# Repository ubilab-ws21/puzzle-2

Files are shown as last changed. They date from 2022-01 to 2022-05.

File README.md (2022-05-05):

# Team 2: Time will guide you!

## Contents
- [Story Overview](#1)
- [The Puzzle](#2)
- [Use Case Scenario](#3)
- [System Overview](#4)
- [Project Workflow](#5)
- [Hardware Overview](#6)
  - [Electronic Components](#7)
  - [The Box](#8) 
- [Software Overview](#9)
  - [Testing Individual Modules](#10)
  - [Building the Main Program](#11)
  - [Configuring OTA](#12)
  - [Establishing MQTT Communication](#13) 
- [References](#14)

## Story Overview 
A Solar strom themed Escape Room where players have to solve puzzles to get out of it. In the year 2032, the world revolving around automation and high-end technology. One fine day, a Solar Storm hits the city and all the servers and digital systems starts to fail there is a power breakdown. The players are stuck inside a server room having limited emergency backup. The goal is to upload the software to the server in order to get things back in place.   

## The Puzzle 
We are building a puzzle for the server room of the Solar Storm themed Escape Room in the Ubiquitous Laboratory Area-079 Escape Room. The puzzle is designed in regard to access the power delivery system which will be powering the automated door to open the server room and power up the server which contains the corrupted software. The emergency power backup can power up only a single server and if wrong switches are turned on the backup will drain out. 

The power switches are protected by a tap-tap pattern for which the players have to be aware and take the hints from the previous puzzle. Once you get the pattern right you get access to the power switches. But, there are lots of switches and you need to turn on few of them. One wrong switch can drain out the emergency backup. The order of the switches which needs to be turned on will be given by the puzzle displayed in the OLED Display. You get the right sequence of switches, the server room door opens and the server turns on.

## Use Case Scenario 
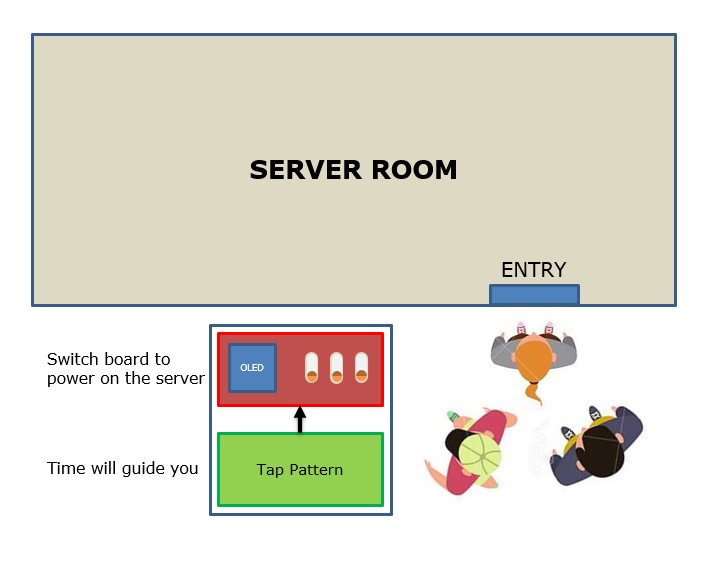
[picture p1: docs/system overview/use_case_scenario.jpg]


## System Overview 
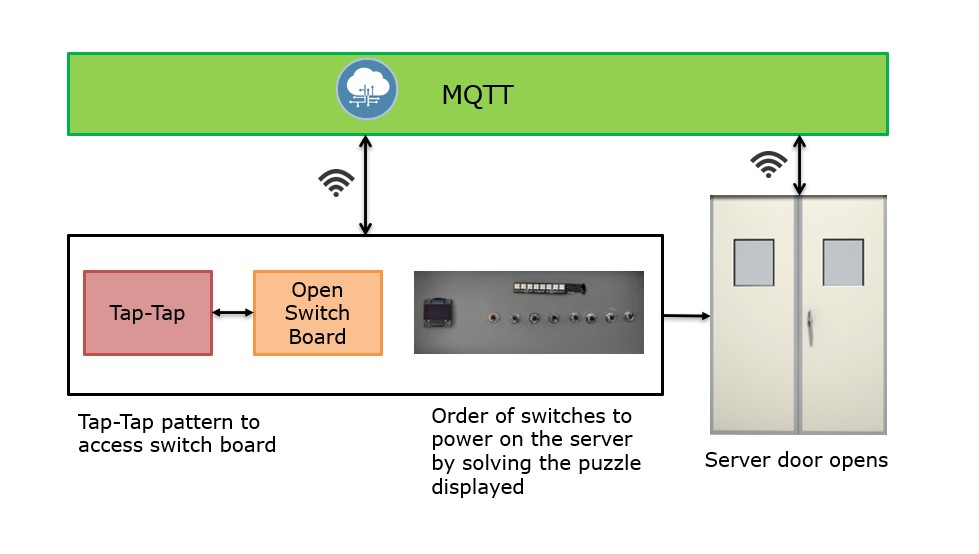
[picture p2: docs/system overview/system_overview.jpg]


## Project Workflow 
- [x] Figuring the puzzle according to the story
- [x] Creating a Bill of Materials (BOM)
- [x] Starting with ESP32 Programming and Basics of MQTT 
- [x] First tour of Escape Room
- [x] Testing all components
- [x] Preparing the circuit
- [x] Program the ESP Board
- [x] Prepare 3D Model
- [x] Print 3D Model
- [x] Design the outer casing
- [x] Assemble the outer casing
- [x] Solder the circuit in PCB
- [x] Assembling all components 
- [x] Testing and Bug Fixing
- [x] Prototype Presentation
- [x] Final Tweaking and Testing
- [x] Final run and presentation

## Hardware Overview 

##### Electronic Components 
- ESP-32 Microcontroller
- Servo Motor
- Piezo Buzzer
- OLED Display
- Toggle Switches
- 8x5050 RGB LED Strip
- Printed Circuit Board
- Connecting Wires

For more details, check [Bill of Materials](https://github.com/ubilab-ws21/puzzle-2/tree/main/docs/BOM).

##### The Box 
The outer casing and the servo hinge was designed using 3D Modelling. The model files can be found [here](https://github.com/ubilab-ws21/puzzle-2/tree/main/design).

## Software Overview 

##### Testing Individual Modules 
Firstly, we tested all the components and modules individually for better integration of our project. Each modules were tested with Arduino for understanding the basic functionality and then tested with ESP32 to check the compatibility. The codes for testing can be found [here](https://github.com/ubilab-ws21/puzzle-2/tree/main/src/test).

##### Building the Main Program 
Then, we integrated all the modules and modified in a single program to be fired up in the ESP32. The program manages the worflow of the puzzle and maintains proper communication with the MQTT server. It is also programmed in such a way that the ESP32 can receives updates Over-the-air. The main code can be found [here](https://github.com/ubilab-ws21/puzzle-2/tree/main/src/main). 

##### Configuring OTA 
In order to receive updates Over-the-air, the below function has been called inside the setup loop. The function sets up the host name and password for the ESP32 in the newtork and updates the ESP32 if there is any update request. Also, remember to include the appropriate header file.
```
#include <ArduinoOTA.h>

void setup(){
  ....
  ....
  setupOTA();
}
void loop(){
  ...
  ...
  ArduinoOTA.handle();
}
```
##### Establishing MQTT Communication 
The puzzle workflow totally depends on successful interaction between the operator and the arcape. The operator controls whether the puzzle is to be turned  `on` or `off` depending on the progess of the other puzzles. The programs subscribes from the topic `2/esp` and checks whether the trigger is on/off and works accordingly. Once the puzzle is `on`, the program publishes that the puzzle is `active` in the topics, `2/esp` and `game/puzzle2` for the operator and arcape resp. to understand that the puzzle is active. Otherwise the state is retained to `inactive` state.

###### Communication Format
All messages exchanged between the server and the client is JSON schema: 

```json
{
  "method": "<method>",
  "state": "<state>",
  "data": "<data>"
}
```
where,

| Method  | State | Description |
| :--- | :--- | :--- |
| status  | inactive, active, solved | Describes the current state of the puzzle |
| trigger | on, off | Contols the behaviour of the puzzle |

More information regarding MQTT server and the communication protocols can be found [here](https://github.com/ubilab-ws21/operator/blob/master/README.md).<br/>
The JSON messages received by the server was parsed inside the function `decodeMessage()` and the messages sent to the server was created by the function `createJson()`.

## References 
- [Adafruit NeoPixel 5050](https://learn.adafruit.com/adafruit-neopixel-uberguide/arduino-library-use)
- [Piezo Knock Sensor](https://www.arduino.cc/en/Tutorial/BuiltInExamples/Knock)
- [0.96" I2C OLED Display](https://randomnerdtutorials.com/guide-for-oled-display-with-arduino/)
- [A Guide to ArduinoJSON](https://github.com/bblanchon/ArduinoJson)

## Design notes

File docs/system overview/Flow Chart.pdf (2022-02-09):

# Flow Chart- Puzzle 2

# Puzzle 2A –

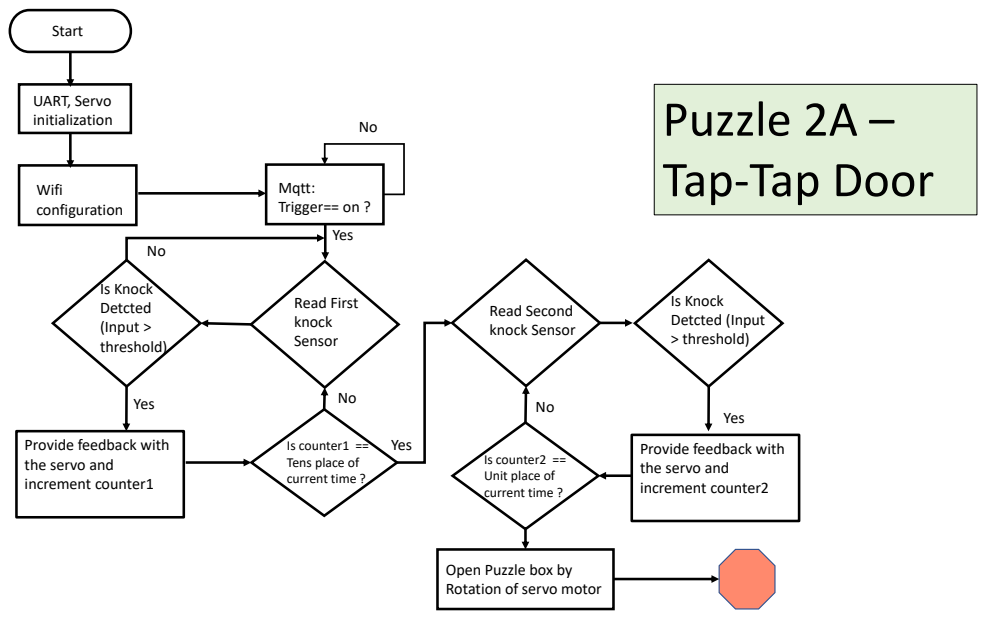
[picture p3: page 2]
Start; UART, Servo initialization; Wifi configuration; Read First knock Sensor; Is Knock Detcted (Input > threshold); Yes; Mqtt:; Tap-Tap Door; Trigger== on ?; Read Second knock Sensor

Provide feedback with
the servo and
increment counter1

Is counter1 ==
Tens place of
current time ?

increment counter2

Is counter2 ==
Unit place of

Open Puzzle box by
Rotation of servo motor

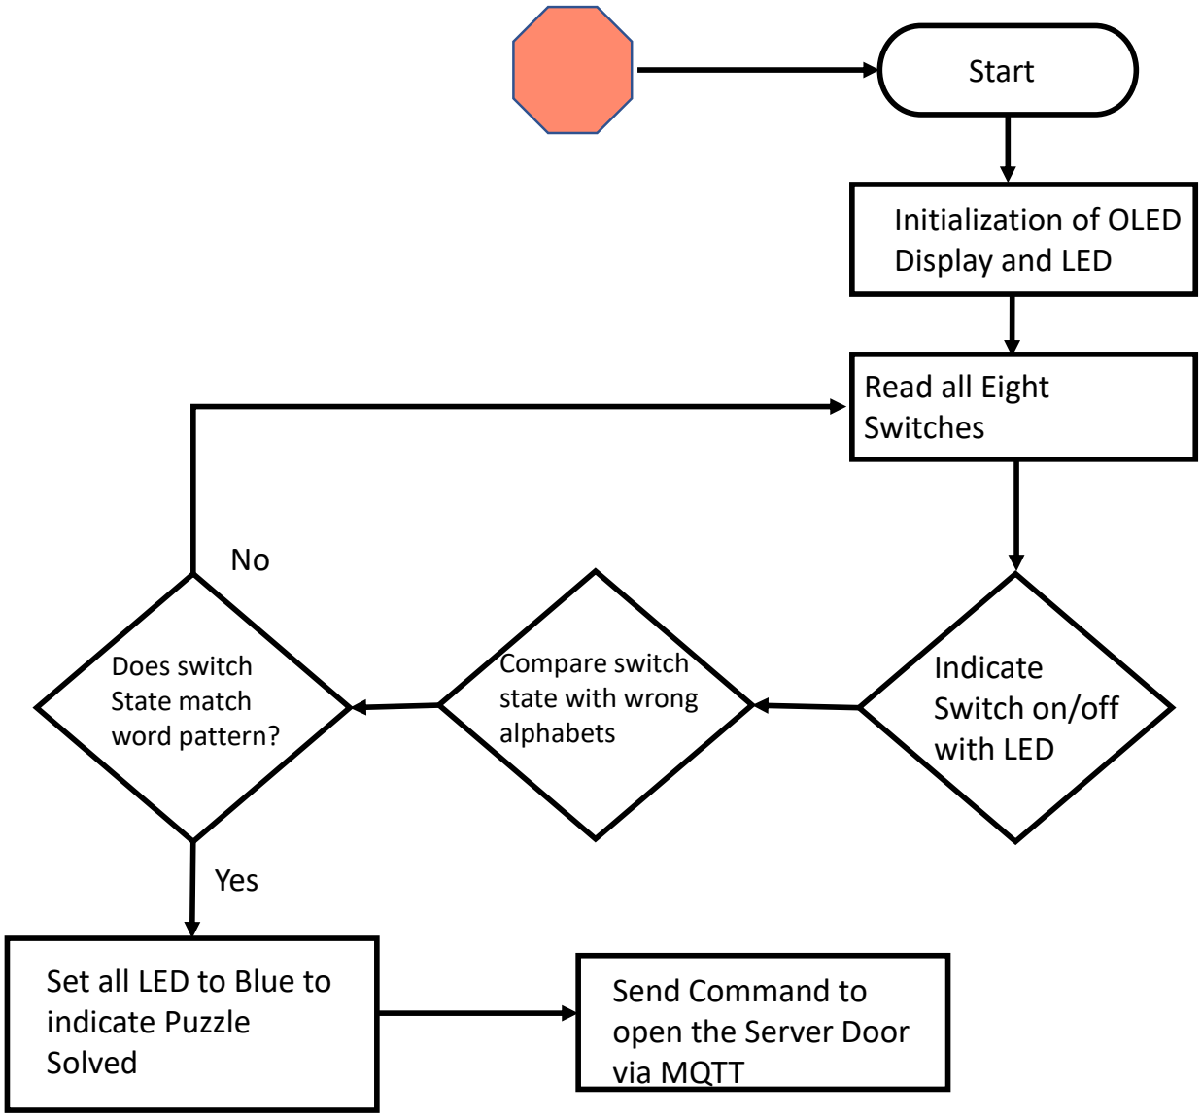
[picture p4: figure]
Start; Read all Eight Switches; Indicate Switch on/off with LED; Compare switch state with wrong alphabets; Initialization of OLED Display and LED; Does switch State match word pattern?; Set all LED to Blue to indicate Puzzle Solved; Send Command to open the Server Door via MQTT; Yes

# Puzzle 2B – Switch Puzzle

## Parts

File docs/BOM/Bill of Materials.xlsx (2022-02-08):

BILL OF MATERIALS - PUZZLE #2
Part | Quantity | Manufacturer | Model | Part Description | Source | Datasheet
MCU | 1 | Espressif Systems | ESP32-PICO-D4 | Rx Txrx Mod Wifi Surface Mount | Octopart (https://octopart.com/esp32-pico-d4-espressif+systems-91243740?r=sp) | ESP32_D4 (https://datasheet.octopart.com/ESP32-PICO-D4-Espressif-Systems-datasheet-109841465.pdf)
Audio buzzer | 3 | Adafruit Industries | 1739 | Audio Buzzer Piezo 1Vp-p 30Vp-p 3.5mA 12Vp-p 85dB 1300Hz to 4000Hz Screw Mount | Octopart (https://octopart.com/1739-adafruit+industries-61582226)
Mechanical switch | 10 | TE Connectivity | 2-1825138-8 | Toggle Switch, Dpdt, On-None-On, Panel, 5 A, 120 V Rohs Compliant: Yes | Octopart (https://octopart.com/2-1825138-8-te+connectivity-39684478) | TE-Connectivity (https://datasheet.octopart.com/2-1825138-8-TE-Connectivity-datasheet-10287660.pdf)
Servo Motors | 2 | DFRobot | SER0006 | 9g Micro Servo 1.6KG/cm Stall Torque 0.12s/60 Degree at 4.8V | Octopart (https://octopart.com/ser0006-dfrobot-47214878)
Toggle Switches | 2 | Adafruit Industries | 1426 | NeoPixel Stick - 8 x WS2812 5050 RGB LED with Integrated Drivers | Octopart (https://octopart.com/1426-adafruit+industries-47253018) | Neopixel-stick-8 (https://uk.pi-supply.com/products/adafruit-neopixel-stick-8-x-ws2812-5050-rgb-led/utm_source=Octopart&utm_medium=Website&utm_campaign=OctopartManufacturer)
OLED Display | 1 | AZ-Delivery | SSD1306 | 0.96" OLED Display with I2C communication | AZ (https://www.az-delivery.de/en/products/0-96zolldisplay) | SSD1306 (https://cdn-shop.adafruit.com/datasheets/SSD1306.pdf)

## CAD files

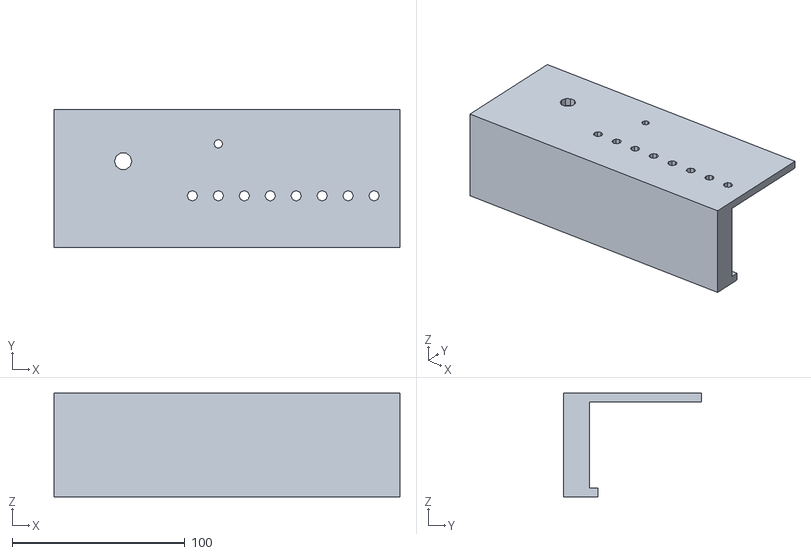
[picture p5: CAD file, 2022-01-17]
design/insideplate_in_mm.stl
200.0 x 80.0 x 60.0

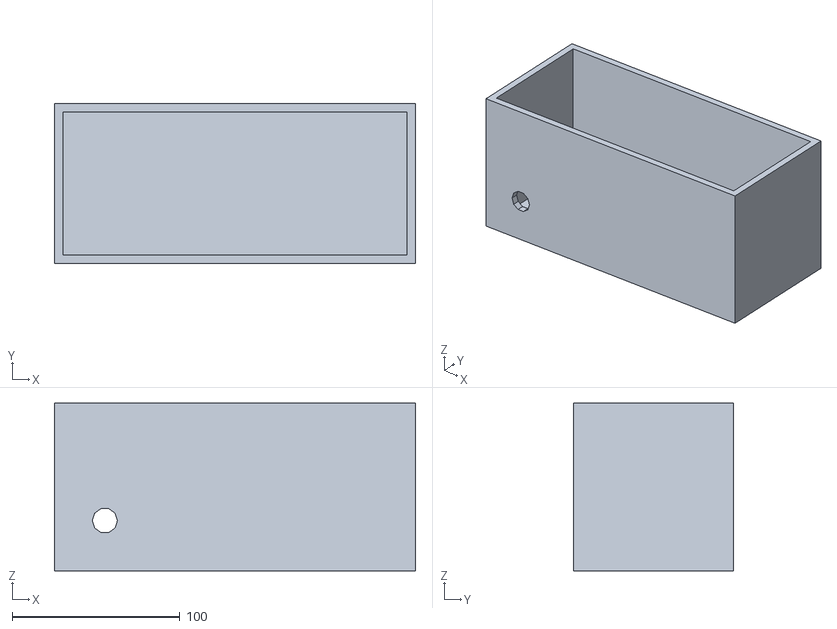
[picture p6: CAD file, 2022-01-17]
design/outsidebox_in_mm.stl
215.0 x 95.0 x 100.0

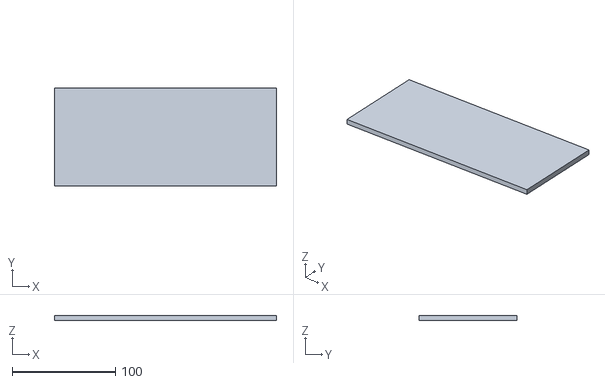
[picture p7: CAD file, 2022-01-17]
design/coverplate_in_mm.stl
215.0 x 95.0 x 5.00

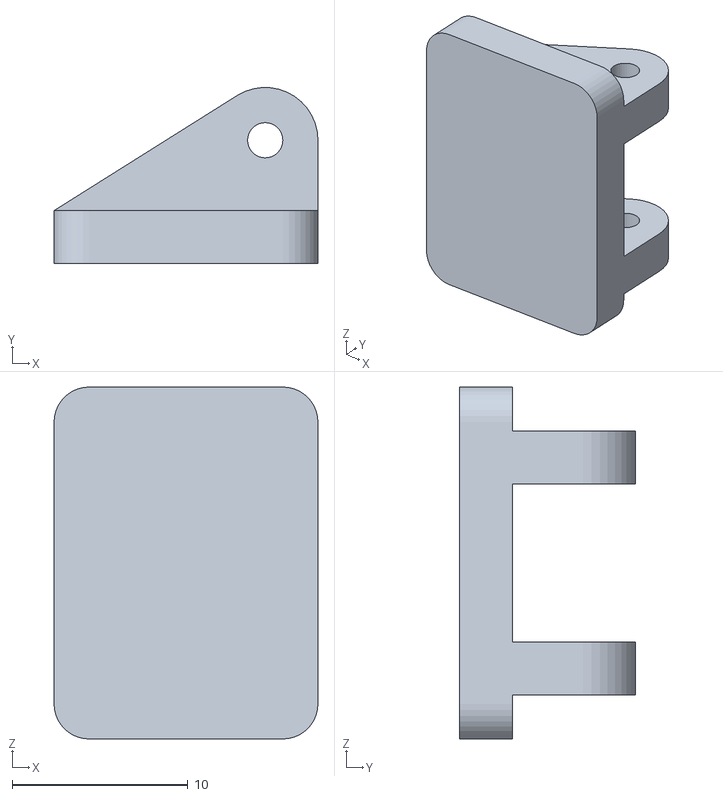
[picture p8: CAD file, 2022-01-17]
design/Hinge_Single_Piece.STL
15.0 x 9.99 x 20.0

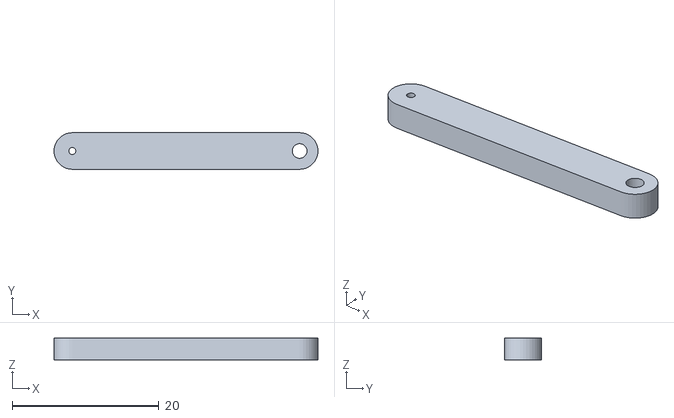
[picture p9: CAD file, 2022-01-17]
design/Push_Rod.STL
36.0 x 5.00 x 3.00

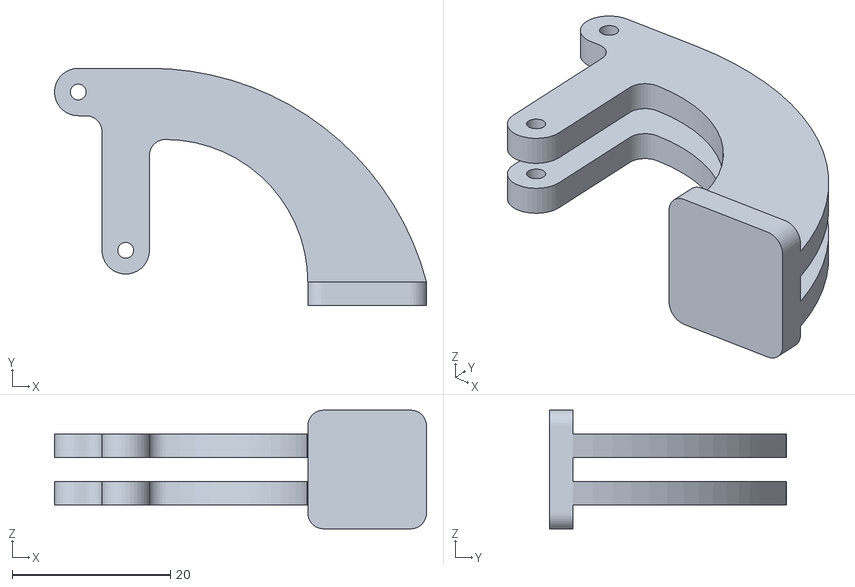
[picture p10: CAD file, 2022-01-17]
design/Horn_Single_Piece.STL
47.0 x 30.0 x 15.0

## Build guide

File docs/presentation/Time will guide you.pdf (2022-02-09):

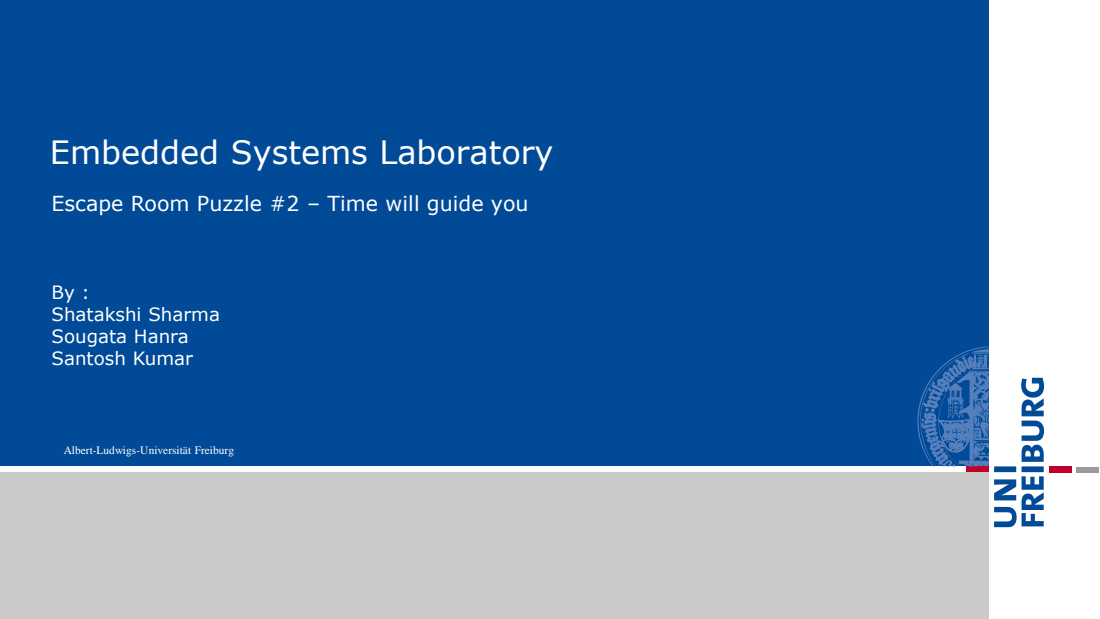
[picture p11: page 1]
By : Shatakshi Sharma Sougata Hanra Santosh Kumar

Embedded Systems Laboratory

Escape Room Puzzle #2 – Time will guide you

Albert-Ludwigs-Universität Freiburg

- SOLAR STORM has occurred! – Hard Shutdown
– Emergency system turns on
– Control Systems malfunctioning
- Main goal
– To get access to the MCB distribution
– Get inside the server room and upload the control software in the server

Story Line!

- Get access to the server room
– Server room is password protected
– The server room emergency power systems have limited resources and can power up only the system. One wrong switch will drain your power system
– The power system switch boards are protected by a Tap-Tap pattern guide by the “Time”
– Once you get access to the MCB distribution, solve the puzzle displayed in the OLED display to get the correct order of the switches that has to be turned on in order to get inside the server room

The Puzzle

SERVER ROOM

ENTRY

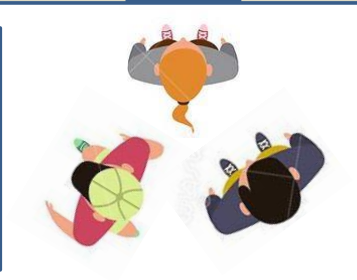
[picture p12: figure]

Tap Pattern

Use case scenario

Switch board to
power on the server

Time will guide you

OLED

- Get access to the MCB distribution board
– Time will guide you
– Use the hints given by the previous puzzle and get the Tap-Tap pattern – Tap-Tap to get to the switch board
- Turn on the switches in right sequence
– The OLED Display will display a puzzle in order to get the right sequence of switches. The right sequence will get you to the server room.
– Hint: Have a good vocabulary!

How to solve the puzzle ??

Tap Pattern

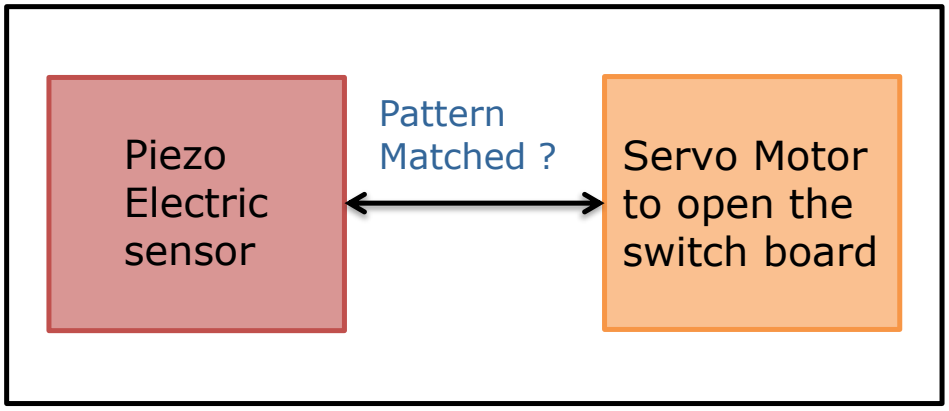
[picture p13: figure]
Piezo Electric sensor; Servo Motor to open the switch board; Pattern Matched ?
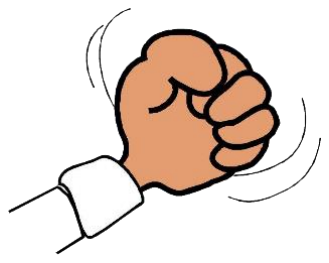
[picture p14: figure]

System Overview

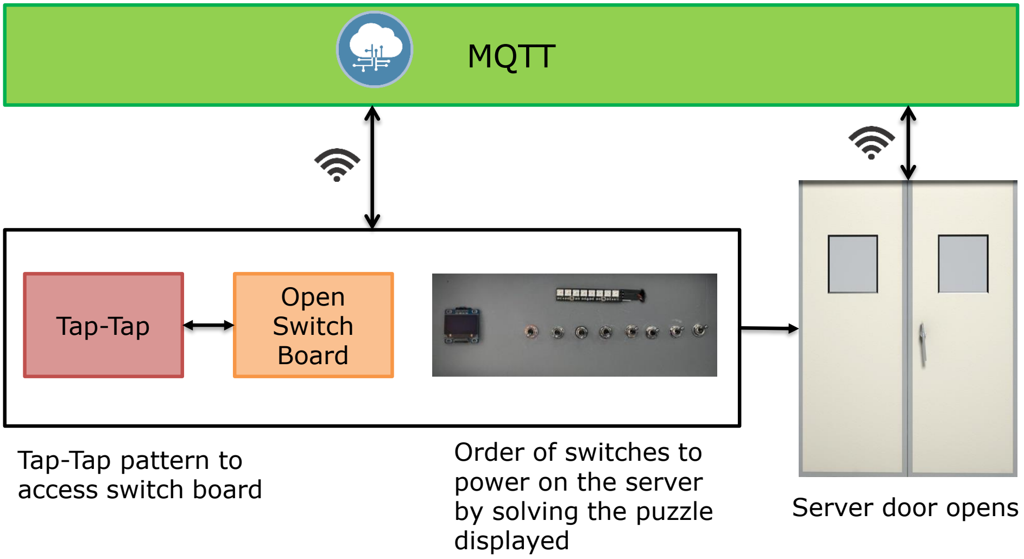
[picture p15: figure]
Open Switch Board; Tap-Tap; MQTT; Order of switches to power on the server by solving the puzzle displayed; Tap-Tap pattern to; access switch board; Server door opens

Thank You !!

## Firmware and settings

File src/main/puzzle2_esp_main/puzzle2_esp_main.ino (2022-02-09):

/*################################################################################# 

*          This is the main program for the ESP32 of our puzzle
* 
* There are two puzzle which has to be solved in order to open the server room:
* [1] Knock-Knock Puzzle  : This puzzle has a piezo element to detect the Knock
*                           pattern and unleasd the switch panel.
*                           
* {2] Switch Panel Puzzle : This puzzle has a series of toggle switches which 
*                           has to be turned on/off in a specific pattern which
*                           the player gets by solving the riddle displayed in
*                           the OLED Display.
* 
* When the puzzle is solved, the server room is opened.
* 
* MQTT Communication : There is a constant communication with the operator
*                      and the ARcape for the puzzle to work accordingly.
*                      
* The communication is done via various MQTT Topics:
* [1] 2/esp [start, stop] - control the state of the ESP
* [2] game/puzzle2 [inactive, active, solved] - displays hints using arcape
* 
* Authors:
* [1] Sougata Hanra
* [2] Santosh Kumar Prabhulingaiah
* [3] Shatakshi Sharma
   
#################################################################################*/

#include <WiFi.h>
#include <Wire.h>
#include "time.h"
#include <ESPmDNS.h>
#include <ESP32Servo.h>
#include <ArduinoOTA.h>
#include <ArduinoJson.h>
#include <Adafruit_GFX.h>
#include <PubSubClient.h>
#include <Adafruit_SSD1306.h>
#include <Adafruit_NeoPixel.h>


/*********************
     Piezo Sensor
*********************/
int Puzzle = 0;
int checkZero = 0;
int piezoFlag = 0;
// these constants won't change:
const int knockSensorL = 32; // the left piezo is connected to analog pin 0
const int knockSensorR = 34; //the right piezo is connected to analog pin 1
const int threshold = 200;  // threshold value to decide when the detected sound is a knock or not
// these variables will change:
int count1 = 0;
int count2 = 0;
int sensorReadingL = 0;   // variable to store the value read from the left sensor pin
int sensorReadingR = 0;   // variable to store the value read from the right sensor pin


/*********************
        Servo
*********************/
Servo servo;  // create servo object to control a servo
// 16 servo objects can be created on the ESP32

int pos = 0;    // variable to store the servo position
// Recommended PWM GPIO pins on the ESP32 include 2,4,12-19,21-23,25-27,32-33 
int servoPin = 19;
int servoFlag = 0;

 
/*********************
     NeoPixel
*********************/
#define PIN 23          // Which pin on the Arduino is connected to the NeoPixels?
#define NUMPIXELS 8     // Number of Pixels in NeoPixel
Adafruit_NeoPixel pixels(NUMPIXELS, PIN, NEO_GRB + NEO_KHZ800);
#define DELAYVAL 500    // Time (in milliseconds) to pause between pixels


/*********************
     Switch Panel
*********************/
// Pins of toggle switches
int button[] = {13,27,26,33,35,15,4,18};


/*********************
     OLED Display
*********************/
#define SCREEN_WIDTH 128         // OLED display width, in pixels
#define SCREEN_HEIGHT 64         // OLED display height, in pixels
Adafruit_SSD1306 display(SCREEN_WIDTH, SCREEN_HEIGHT, &Wire, -1);   // Declaration for an SSD1306 display connected to I2C (SDA, SCL pins)


/*********************
  Other Declarations
*********************/
//Flag to activate the puzzle
bool puzzleStart;

//Use Internet connection
#define useNetwork

//Local Time Variables
const char* ntpServer = "pool.ntp.org";
const long  gmtOffset_sec = 3600;
const int   daylightOffset_sec = 3600;
int CurrentHour, UnitHour, TenHour;
int hourNow=12;

//Create a JSON Document to read MQTT messages
StaticJsonDocument<300> mqtt_decoder;

//Puzzle Declarations
bool puzzleSolved=false;
int randNo, bitCode;
char *newWord; 
char *words[] = {"eeltcric","nteowrks","magnteci","paritcel","dissaetr","collsape"};
int bitCodes[6][NUMPIXELS] = {{1,0,0,0,0,1,1,1},
                              {1,0,0,0,0,1,1,1},
                              {1,1,1,1,0,0,0,0},
                              {1,1,1,0,0,1,0,0},
                              {1,1,1,0,0,0,0,1},
                              {1,1,1,1,0,0,0,1}};
int code[NUMPIXELS] = {0,0,0,0,0,0,0,0};
int currCode[NUMPIXELS] = {0,0,0,0,0,0,0,0};

boolean CodeCmp(int a[NUMPIXELS], int b[NUMPIXELS])
{
  for(int i=0;i<NUMPIXELS;i++) if(a[i]!=b[i]) return false;
  return true;
}

// Speed of Serial Communication
#define SERIAL_COMSPEED 9600

// Credentials for network SSID and PWD
#define SSID "ubilab_wifi"
#define PWD "ohg4xah3oufohreiPe7e"

// Device can be found on the network using this name
#define NAME "Puzzle2-ESP0"  //Name of the ESP
#define OTA_PWD "sss21"      // PWD for OTA

// MQTT Server
#define mqtt_server "10.8.166.20"
WiFiClient puzzle_2;
PubSubClient client(puzzle_2);
bool retained = true;
#define MAX_MSG 50
char msg[MAX_MSG] = {'\0'};

void reconnect() {
  while (!client.connected()) {
    Serial.print("Attempting MQTT connection...");
    if (client.connect("puzzle-2")) {
      Serial.println("connected");
      client.subscribe("2/esp");
      client.setCallback(callback);
    }else{
      Serial.print("failed, rc=");
      Serial.print(client.state());
    }
  }
}


void setup() {
  // Initialize the Serial Port
  Serial.begin(SERIAL_COMSPEED);
  
  #ifdef useNetwork
    /*********************
       WiFi Connection
     *********************/
    Serial.print("Connecting to ");
    Serial.println(SSID);
    // Set name passed to AP while connection
    WiFi.setHostname(NAME);
    // Connect to AP
    WiFi.begin(SSID, PWD);
    // Wait while not connected
    while (WiFi.status() != WL_CONNECTED) {
      delay(500); Serial.print(".");
    }
    // Print IP
    Serial.println("\nWiFi connected.\nIP Adress: ");
    Serial.println(WiFi.localIP());
  
    /*********************
          MQTT Server
    *********************/
    client.setServer(mqtt_server, 1883);
    client.setCallback(callback);
    client.subscribe("2/esp");
    
    /*********************
       multicast DNS
    *********************/
    // Set name of this device
    if (!MDNS.begin(NAME)) {
      Serial.println("Setting up MDNS responder!");
    }
    // The service this device hosts (example)
    MDNS.addService("_escape", "_tcp", 2000);
    setupOTA();

    /*********************
        Config Time
    *********************/ 
    configTime(gmtOffset_sec, daylightOffset_sec, ntpServer);
    getCurrentHour(); 
    hourNow = getCurrentHour();
 #endif
  
  /**************************
   Switches Mode Initialize
  **************************/
  for(int j=0; j<NUMPIXELS; j++)
  {
    pinMode(button[j],INPUT);
    currCode[j] = digitalRead(button[j]);
  }

  /*********************
          Servos
  *********************/
  servo.setPeriodHertz(50);  // standard 50 hz servo
  servo.attach(servoPin, 500, 2400);
  servo.write(160);  //set to default position 

  /*********************
  Config Time Variables
  *********************/ 
  // Init and get the time
  UnitHour = hourNow%10;
  TenHour =(hourNow/10)%10;
 
  
  /*********************
    Puzzle Initialize
  *********************/
  do
  {
    randNo = random(0,5);
    newWord = words[randNo];
    for(int k=0; k<NUMPIXELS; k++)
    {
      code[k] = bitCodes[randNo][k];
    }
  }while(CodeCmp(currCode,code) == true);

  
  /*********************
       OLED Display
  *********************/
  if(!display.begin(SSD1306_SWITCHCAPVCC, 0x3C)) {       // Address 0x3D for 128x64
    Serial.println(F("SSD1306 allocation failed"));
    for(;;);
  }
  delay(2000);
  display.clearDisplay();
  display.setTextSize(1);
  display.setTextColor(WHITE);
  display.setCursor(0,10);
  display.println("Guess the word?");
  display.println("Note the wrong positions\n");
  delay(100);
  display.setTextSize(2);
  display.println(newWord);  
  display.display(); 
  delay(100); 

  /*********************
   NeoPixel Initialize
  *********************/
  pixels.begin();   
  pixels.clear();
  delay(500);  
}


void loop() {
  #ifdef useNetwork
    // Needs to be called to check for external update request
    ArduinoOTA.handle();
    //MQTT Loop
    if (!client.connected()) {
      reconnect();
    }
    client.loop();
    if(puzzleSolved==true){
      client.publish("game/puzzle2",createJson("status", "solved", ""));    
      client.publish("2/esp",createJson("status", "solved", ""));
    }
  #endif

  while(puzzleStart && !puzzleSolved){
    /*********************
       Piezo Sensor
    *********************/
    sensorReadingL = analogRead(knockSensorL);
    sensorReadingR = analogRead(knockSensorR);
     
    if(UnitHour==0) checkZero=1;
     
    if ((sensorReadingL >= threshold)&&(Puzzle == 0)){ 
      count1++;
      Serial.println("Knock1"); 
      makeBuzz();
      if (count1 >= TenHour) {
       Serial.println("knock 1 routine done");
       Puzzle = 1;
      }
    }
        
    else if ((sensorReadingR >= threshold)&&(Puzzle == 1)&&(UnitHour>0)){   
      count2++;  
      Serial.println("Knock2");
      makeBuzz();   
      if (count2 >= UnitHour) {
        Serial.println("knock 2 routine done");
        Puzzle = 2;
       }
     }
      
    else if (Puzzle == 2 ||(Puzzle == 1 && checkZero == 1)){  
    /*********************
             Servo
    *********************/
     for (pos = 160; pos >= 0; pos -= 1) { // goes from 0 degrees to 120 degrees in steps of 1 degree
      servo.write(pos);    // tell servo to go to position in variable 'pos'
      delay(15);     // waits 15ms for the servo to reach the position
      Puzzle == 3;
     } 
     servo.detach();
     count1=0;
     count2=0;
    }
    
    //Checks whether the switch sequence matches or not
    if(CodeCmp(currCode,code) == true)
    {
      puzzleSolved = true;
      pixels.fill(pixels.Color(0, 0, 255));
      pixels.show();
      display.clearDisplay();
      display.setTextSize(2);
      display.setTextColor(WHITE);
      display.setCursor(0,10);
      display.println("Puzzle\n");
      display.println("Solved\n");
      display.display();
    }
  
    //Reads the current sequence of switches
    for(int j=0;j<NUMPIXELS; j++)
    {
      currCode[j] = digitalRead(button[j]);
    }
  
    for(int i=0;i<NUMPIXELS;i++)   
    {
       pixels.setBrightness(10);
       if(currCode[i] == 1 && !puzzleSolved)
       {
         pixels.setPixelColor(((NUMPIXELS-1)-i), pixels.Color(0, 255, 0));
         pixels.show();
       }
       else if (currCode[i] == 0 && !puzzleSolved)
       {
         pixels.setPixelColor(((NUMPIXELS-1)-i), pixels.Color(255, 0, 0));
         pixels.show();
       }
    }
  }
}

/*****************************
    Feedback for knock
*****************************/ 
void makeBuzz(){
  servo.write(130);
  delay(150);
  servo.write(160);
}

/*****************************
  Funtion to get Local Time
*****************************/ 
int getCurrentHour(){
  struct tm timeinfo;
  if(!getLocalTime(&timeinfo)){
    Serial.println("Failed to obtain time");
    return 0;
  }
 CurrentHour = timeinfo.tm_hour;
 return CurrentHour;
}

/**************************
     MQTT Callback
**************************/
void callback(char* topic, byte* message, unsigned int length) {
  // Convert to cstring
  int len = min((int)length, (int)(MAX_MSG-1));
  memcpy(&msg[0], message, len);
  msg[len] = '\0'; 

  Serial.printf("MQTT msg on topic: %s: %s\n", topic, &msg);
  decodeMessage(topic, msg);
}

/**************************
     Setup OTA Updates
**************************/
void setupOTA() {
  ArduinoOTA.setHostname(NAME);           
  ArduinoOTA.setPassword(OTA_PWD);        
  ArduinoOTA.onStart([]() {               
    Serial.println("Start updating");
  });
  ArduinoOTA.onEnd([]() {                 
    Serial.println("Finished updating");
  });
  ArduinoOTA.onProgress([](unsigned int progress, unsigned int total) {    
    Serial.printf("Update at %u % \n", progress / (total / 100));
  });
  ArduinoOTA.onError([](ota_error_t error) {     
    Serial.println("Error updating");
    esp_restart();
  });
  ArduinoOTA.begin();     
}

/*************************************
   Function to create JSON message
*************************************/
char* createJson(char* method_s, char* state_s, char* data_s){
  StaticJsonDocument<300> doc;
  doc["method"] = method_s;
  doc["state"] = state_s;
  doc["data"] = data_s;
  static char JSON_String[300];
  serializeJson(doc, JSON_String);
  return JSON_String;
}

/*************************************
   Function to decode JSON message
   and work with Operator commands
*************************************/ 
void decodeMessage(char* topic, char* msg) {
  deserializeJson(mqtt_decoder, msg);
  const char* method_msg = mqtt_decoder["method"];
  const char* state_msg = mqtt_decoder["state"];
  const char* data_msg = mqtt_decoder["data"];
  
  if(strcmp(topic, "2/esp") == 0 && strcmp(method_msg, "trigger") == 0 && strcmp(state_msg, "on") == 0){
    puzzleStart=true;
    for(int k=0;k<5;k++){
      delay(600);
      makeBuzz();
    }
    client.publish("game/puzzle2",createJson("status", "active", ""),retained);
    client.publish("2/esp",createJson("status", "active", ""),retained);
  }
  if(strcmp(topic, "2/esp") == 0 && strcmp(method_msg, "trigger") == 0 && strcmp(state_msg, "off") == 0){
    puzzleStart=false;
    client.publish("game/puzzle2",createJson("status", "inactive", ""),retained);
    client.publish("2/esp",createJson("status", "inactive", ""),retained);
    delay(2000);
    esp_restart();
  }
}

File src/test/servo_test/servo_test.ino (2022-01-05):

/* 
    Servo Test using ESP-32

  [Sweep motion check (0-180-0)]
  
*/

#include <ESP32Servo.h>

Servo myservo;  // create servo object to control a servo
// 16 servo objects can be created on the ESP32

int pos = 0;    // variable to store the servo position
// Recommended PWM GPIO pins on the ESP32 include 2,4,12-19,21-23,25-27,32-33 
int servoPin = 22;

void setup() {
  // Allow allocation of all timers
  ESP32PWM::allocateTimer(0);
  ESP32PWM::allocateTimer(1);
  ESP32PWM::allocateTimer(2);
  ESP32PWM::allocateTimer(3);
  myservo.setPeriodHertz(50);    // standard 50 hz servo
  myservo.attach(servoPin, 500, 2400); // attaches the servo on pin 18 to the servo object
  // using default min/max of 1000us and 2000us
  // different servos may require different min/max settings
  // for an accurate 0 to 180 sweep
}

void loop() {

  for (pos = 0; pos <= 180; pos += 1) { // goes from 0 degrees to 180 degrees
    // in steps of 1 degree
    myservo.write(pos);    // tell servo to go to position in variable 'pos'
    delay(15);             // waits 15ms for the servo to reach the position
  }
  for (pos = 180; pos >= 0; pos -= 1) { // goes from 180 degrees to 0 degrees
    myservo.write(pos);    // tell servo to go to position in variable 'pos'
    delay(15);             // waits 15ms for the servo to reach the position
  }
}

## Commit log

2021-11-30 Add files via upload
    Flow chart for implementation of Code, This pdf contains Flowchart for Tap-Tap puzzle and MCB switch puzzle.
2021-11-30 Add files via upload
    Bill of Materials for Implementation of the System
    [Bill of Materials.xlsx]
2022-02-08 Minor Bug fixes, added MQTT
    [puzzle2_esp_main.ino]
2022-02-09 Flow Chart of the System
